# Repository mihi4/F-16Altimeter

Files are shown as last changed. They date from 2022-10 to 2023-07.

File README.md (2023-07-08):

# F-16 Altimeter

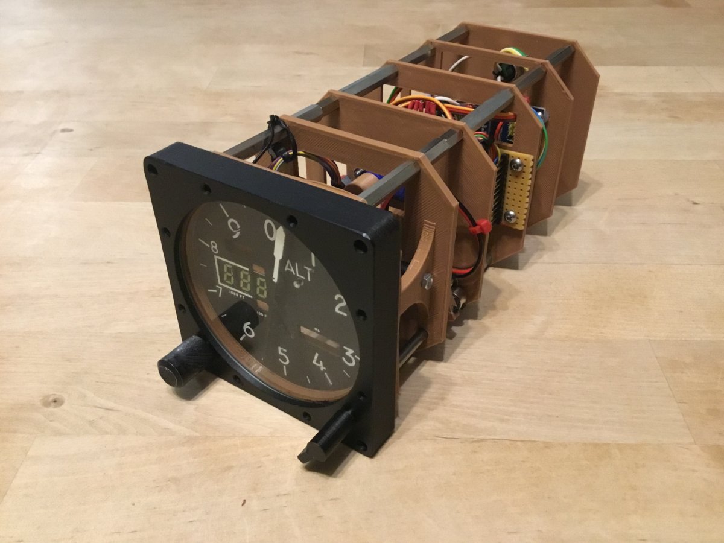
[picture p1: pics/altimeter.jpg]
Altimeter


All the files I created my altimeter from...

* The FCStd*-Files are all parts I created in FreeCAD.  
Not all of them are for 3Dprinting, some are just for reference.

* In the folder "3DprintFiles" are the exported parts as .3mf-files to use in your slicer.  
I'm not sure, if all the parts are up2date, since often I do some changes in FreeCAD without exporting the files afterwards.
Best strategy would be to export each part directly from the FreeCAD files.

* The "arduino" folder holds the sourcecode for the Arduino-side of [BMSAIT](https://github.com/mihi4/BMSAIT) by Robin "HummerX" Bruns.  
You can get the Windows program in the link above.
centerController.ini should be used as configuration file in BMSAIT.

The Nano will drive the Centerconsole instruments, except the ADI and HSI.  
Altimeter, the 2 ASI needles, 4 additional servos of VVI and AOA and the MarkerBeacon

- pin A5: input for rotary push to reset motor
- pin A6: switch for pneu/elec
- pin A7: input to zeroize the stepper 
- pins 2, 3: rotary encoder (2 interrupt pins)
- pins 4, 5, 6, 7: Altimeter continous x27 motor
- pins 8, 9, 10: max7210 for 4+3 7-segment displays
- pins 11, 12, 13, A1, A2, A3, A4: servos for PNEU flag, KIAS, MACH, VVI, AOA, VVIFlag, AOAFlag
- pin A0: marker beacon LED

There are no files for the connectionboard of the LEDMatrixBoard to the displays.  
You will have to find the specific pinout with a multimeter and then solder the right pin of the displays to it.

## !!! Use those files at your own risk !!!

All the files are free to use under the GNUGPLv3

If you find those files useful and would like to support me with an icecream, coffee or pizza, you can use paypal.me to do so ;)  
[Paypal.me](https://paypal.me/MichiHirczy)

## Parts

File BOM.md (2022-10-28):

## Hardware parts used and possible sources for it (mostly Aliexpress)

_needle shaft_: any 2mm rod you can find, I used 2mm spring steel since it was available

_needle motor_: X27.168 stepper motor, available all around the net

_needle zeroize sensor_: [Amazon](https://www.amazon.de/gp/product/B0817FM4BJ)

_PNEU flag shaft_: an 1mm steel rod, again, I'm using 1mm spring steel

_PNEU flag motor_: standard SG90 mini servo

_3 digit 7seg display_: 3312AW common cathode, 0.32" white, [Aliexpress](https://www.aliexpress.com/item/1005003689467554.html)

_5 digit 7seg display_: 0.23" common cathode display, white, [Aliexpress](https://www.aliexpress.com/item/1005003747393244.html)

_Arduino Nano_: nuff said ;)

_Extension board_: just google "Arduino Nano Extension Shield", buy wherever you want

_Display driver_: just google "max 7291 led matrix 8x8"

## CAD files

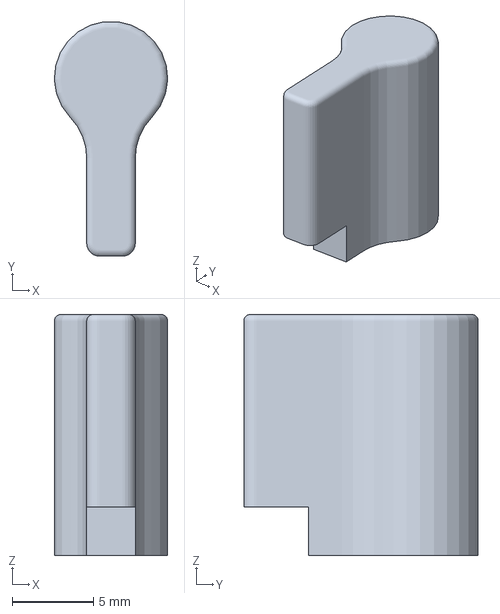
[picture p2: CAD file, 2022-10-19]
3DprintFiles/altimeter-pneuKnob.3mf
7.00 x 14.5 x 14.9 mm

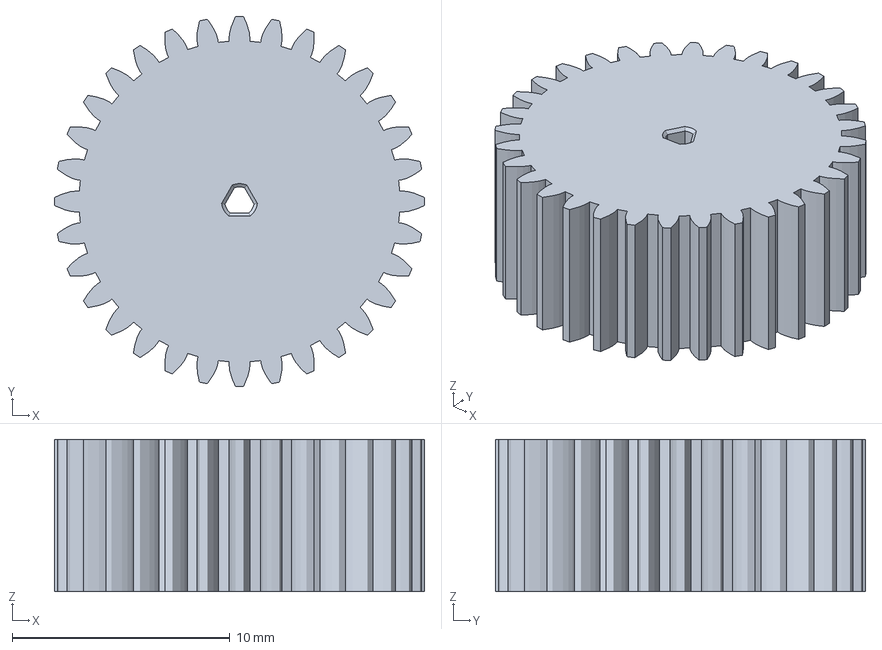
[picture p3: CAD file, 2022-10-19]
3DprintFiles/altimeter-GearBigMod0_5.3mf
17.0 x 17.0 x 7.00 mm

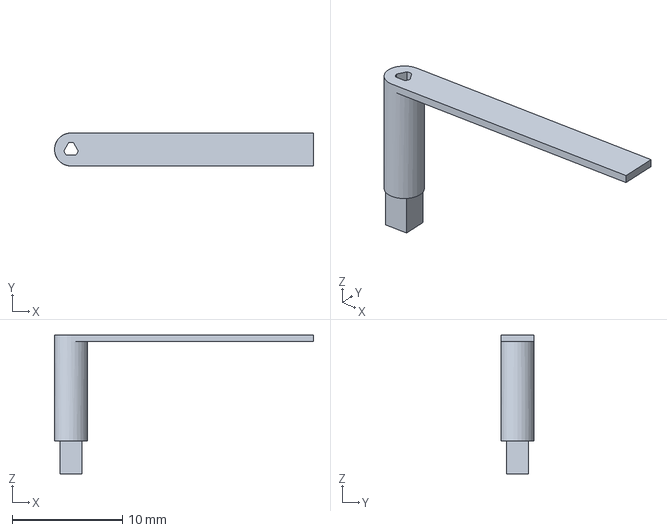
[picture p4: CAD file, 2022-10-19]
3DprintFiles/altimeter-axleConnector.3mf
23.5 x 3.00 x 12.6 mm

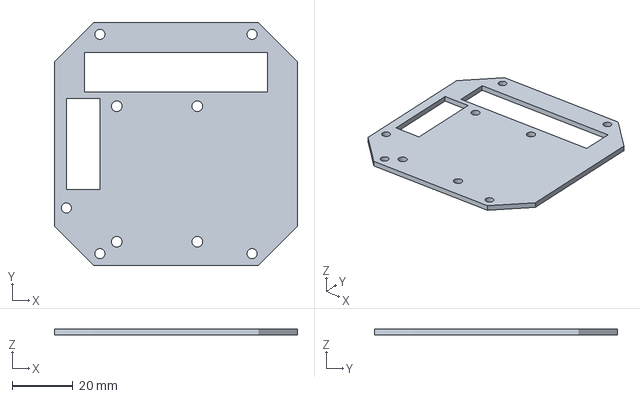
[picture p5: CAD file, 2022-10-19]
3DprintFiles/altimeterParts-MAX7219Plate.3mf
79.8 x 79.8 x 2.00 mm

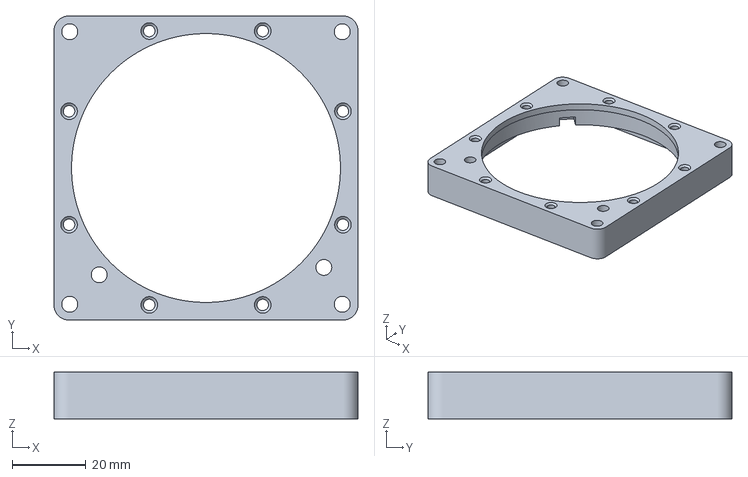
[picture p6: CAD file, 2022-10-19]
3DprintFiles/altimeterParts-Frontplate.3mf
82.5 x 82.5 x 12.7 mm

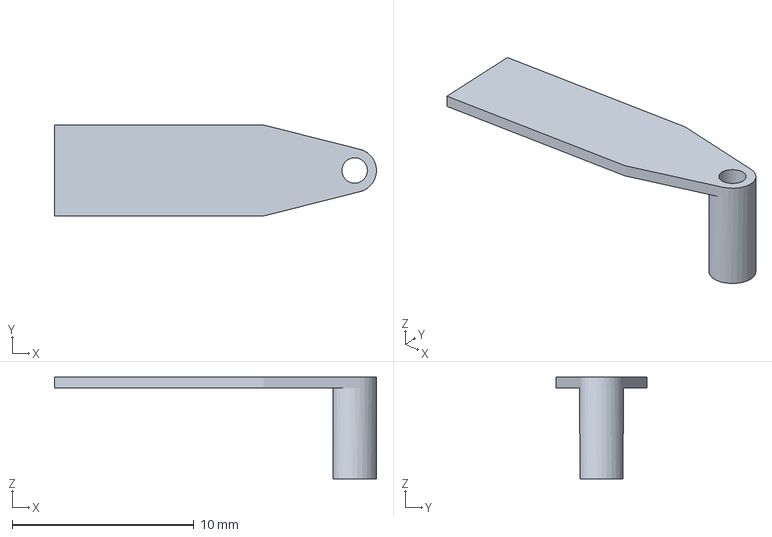
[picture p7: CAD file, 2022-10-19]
3DprintFiles/altimeter-pneuFlag.3mf
17.7 x 5.00 x 5.60 mm

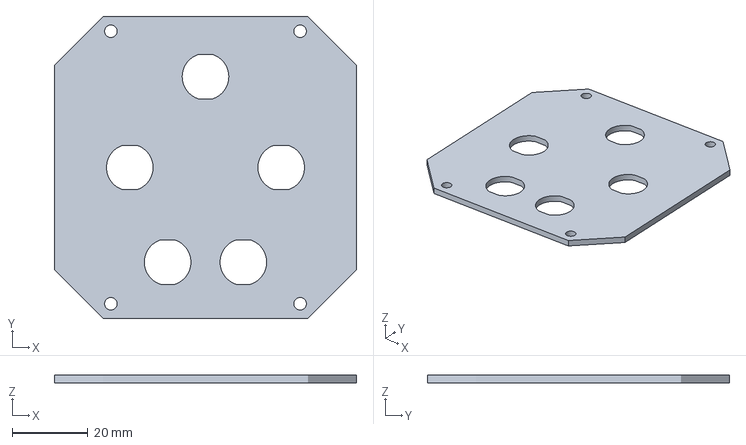
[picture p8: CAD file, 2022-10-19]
3DprintFiles/altimeterParts-ConnectorPlate.3mf
79.8 x 79.8 x 2.00 mm

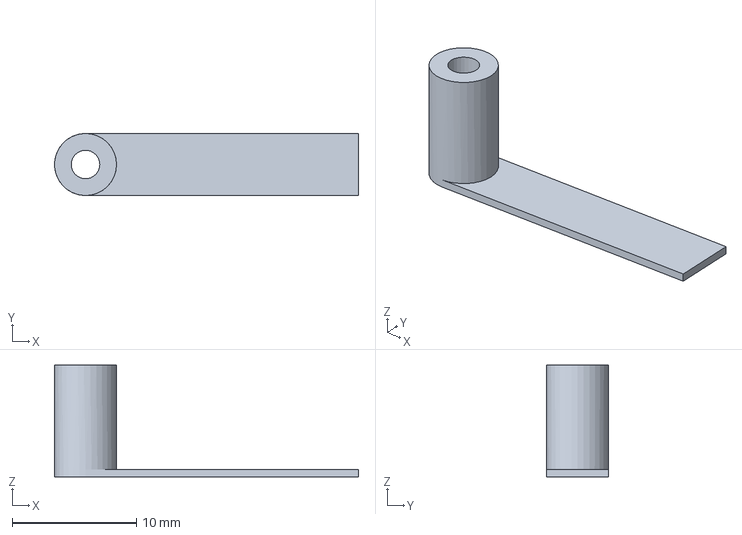
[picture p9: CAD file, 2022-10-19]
3DprintFiles/altimeter-SensorPin.3mf
24.5 x 5.00 x 9.00 mm

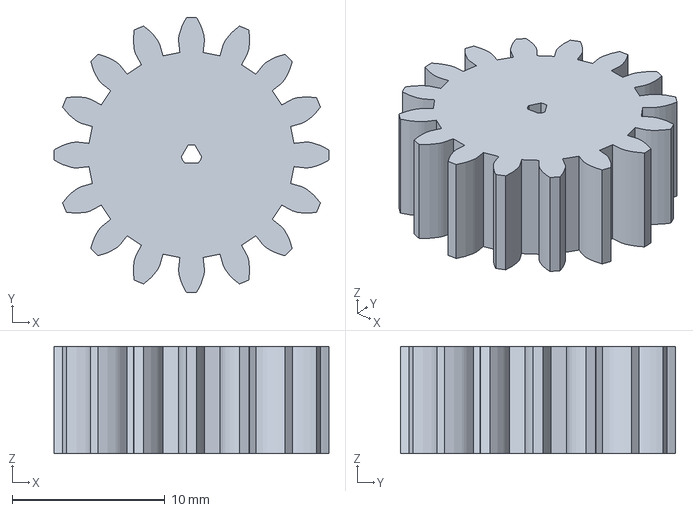
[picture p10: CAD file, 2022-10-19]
3DprintFiles/altimeter-GearBigStepper.3mf
18.0 x 18.0 x 7.00 mm

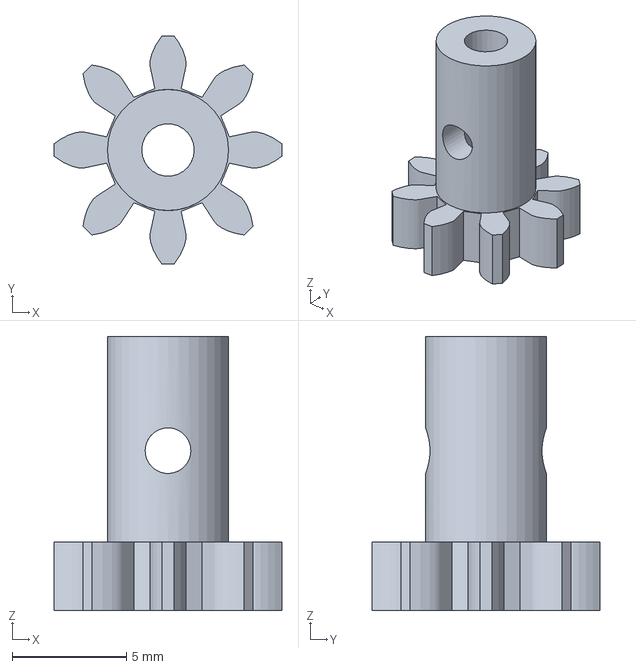
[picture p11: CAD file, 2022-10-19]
3DprintFiles/altimeter-gearSmallNeedle.3mf
9.99 x 9.99 x 12.0 mm

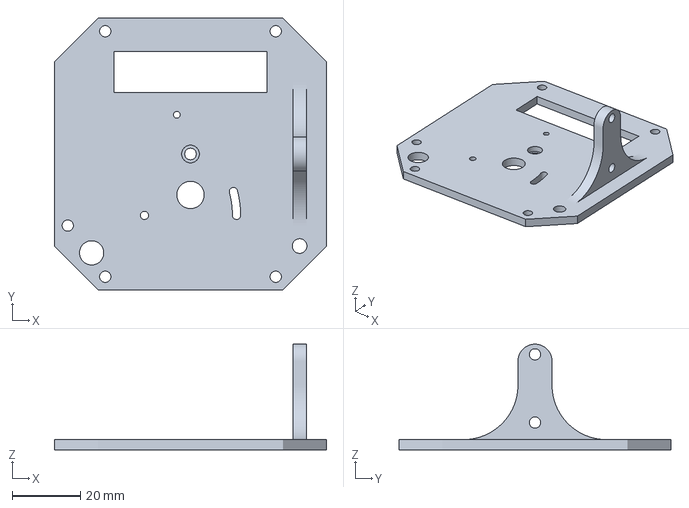
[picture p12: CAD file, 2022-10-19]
3DprintFiles/altimeterParts-StepperPlate.3mf
79.8 x 79.8 x 31.0 mm

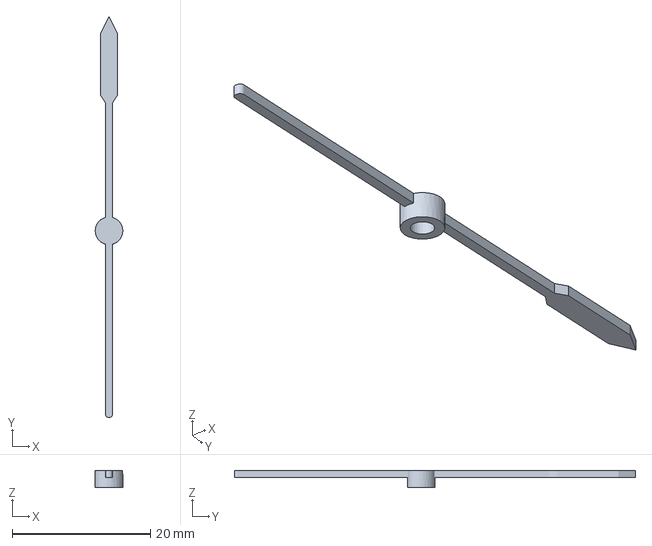
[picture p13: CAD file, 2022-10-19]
3DprintFiles/altimeter-Needle.3mf
4.00 x 58.0 x 2.50 mm

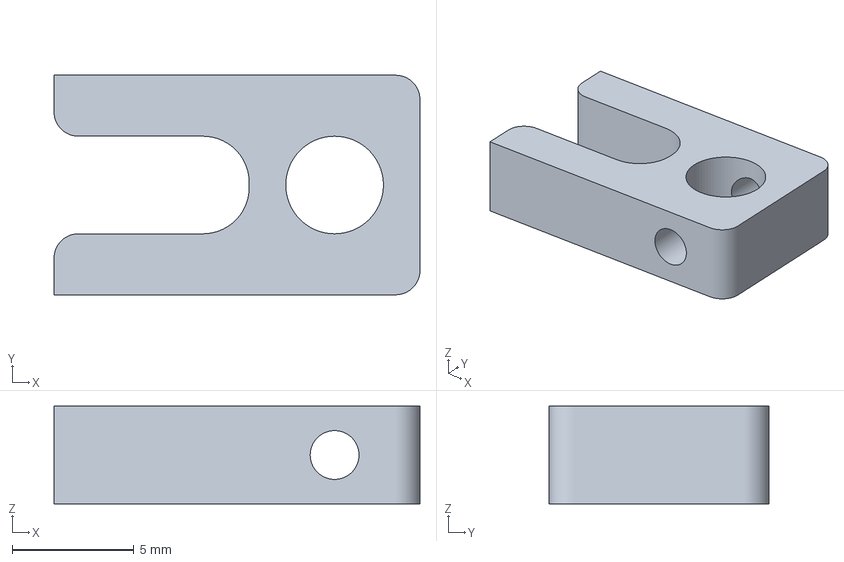
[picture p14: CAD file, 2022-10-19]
3DprintFiles/altimeter-pneuActivator.3mf
15.0 x 9.00 x 4.00 mm

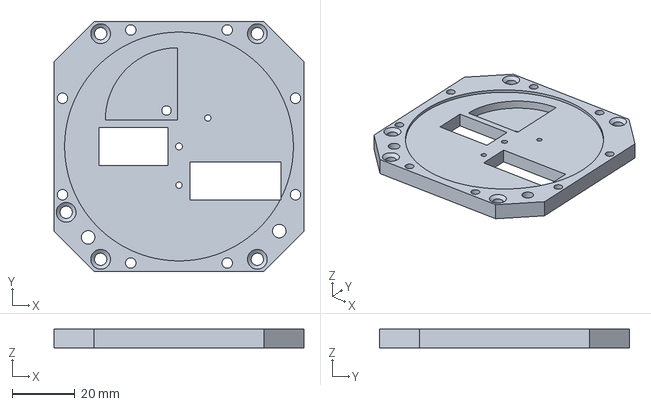
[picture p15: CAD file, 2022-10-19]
3DprintFiles/altimeterParts-Faceplate.3mf
79.8 x 79.8 x 6.00 mm

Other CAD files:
3DprintFiles/altimeterParts-Servoplate.3mf
3DprintFiles/altimeterParts-NanoShieldPlate.3mf
3DprintFiles/altimeter-GearSmallMod0_5.3mf
3DprintFiles/altimeter-GearSmallStandalone.3mf
3DprintFiles/altimeterParts-ServoAdapter.3mf

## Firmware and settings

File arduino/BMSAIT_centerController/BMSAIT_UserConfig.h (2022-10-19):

// Version: 1.3.11    29.3.22



//MODULE SELECTION - uncomment the modules you want to use.
   
  // FIXXXME #define LED               //drive LEDs
  //#define LEDMatrix         //drive LED Matrix using a MAX7219 controller
  //#define LED_MM5451        //drive LEDs through one or more MM5451 controller
  //#define LCD               //drive LCD display
  #define SSegMAX7219       //drive 7-Segment displays via MAX7219 controller
  //#define SSegTM1637        //drive 7-Segment displays via TM1367 controller
  //#define SLx2016           //drive 4-digit 5x7 dotmatrix modules
  #define ServoMotor        //drive servo motors directly connected to the arduino
  //#define ServoPWM          //drive multiple servo motors via pwm shield
  //#define StepperBYJ        //drive stepper motor 28BYJ-48
  //#define StepperX27        //drive stepper motor X27.168
  //#define CompassX27        //drive a compass with a Xxx.xxx -class stepper motor
  #define AltimeterX27      //drive the altimeter needle with a Xxx.xxx -class stepper motor
  //#define StepperVID        //drive multiple stepper motors X25.168 with a VID66-06 controller
  //#define MotorPoti         //motor-driven poti control
  //#define OLED              //display data on an OLED display
  //#define SpeedBrake        //Enable display of the SpeedBrake indicator on an 128x64 OLED display (DEDunino)
  //#define FuelFlowIndicator //Enable display of the FuelFlow indicator on an 128x64 OLED display (DEDunino)
  //#define DED_PFL           //Enable display of DED or PFL on an 254x64 OLED display (DEDunino)
  //#define Switches          //use the arduino to read switch positions and send keyboard commands
  //#define ButtonMatrix      //use the arduino to read switch positions and send keyboard commands
  #define RotEncoder        //use the arduino to read rotary encoders and send keyboard commands
  //#define AnalogAxis        //use the arduino to read analog resistors and sync this with a gamecontroller axis
  //#define Lighting          //software controlled backlighting
  //#define NewDevice         //placeholder. Use this line to activate your own code to drive other, specific hardware  


//BASIC SETTINGS
  #define BAUDRATE 57600         // serial connection speed
  #define POLLTIME 120           // set time between PULL data requests
  #define PULLTIMEOUT 50         // set time to wait for a requested data update defaut: 30ms
  //#define PRIORITIZE_OUTPUT    //uncomment this to put a stress on fast update of outputs (should be used for motors to allow smoother movements)
  //#define PRIORITIZE_INPUT     //uncomment this to put a stress on fast er poll of inputs (switches/Buttons) 
  const char ID[]= "BMSAIT_centerController"; //Set the ID for this arduino program. Use any string. The program will use this ID to check in with the BMSAIT windows application
 
//BOARD SELECTION

  //#define UNO         //uncomment this if this sketch will be loaded on an UNO
  #define NANO        //uncomment this if this sketch will be loaded on an NANO
  //#define MICRO       //uncomment this if this sketch will be loaded on an MICRO
  //#define LEONARDO    //uncomment this if this sketch will be loaded on an LEONARDO
  //#define MEGA        //uncomment this if this sketch will be loaded on an MEGA
  //#define DUE         //uncomment this if this sketch will be loaded on an DUE (connected via programming port)
  //#define DUE_NATIVE  //uncomment this if this sketch will be loaded on an DUE (connected via native port)
  //#define ESP         //uncomment this if this sketch will be loaded on an ESP32 or ESP8266
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

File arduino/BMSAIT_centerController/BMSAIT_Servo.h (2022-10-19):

// settings and functions to drive servo motors (directly connected to the arduino)
// V1.3.7 26.09.2021

//target= reference link to the line of the servodata table of this module
//ref2= not used
//ref3= not used
//ref4= not used
//ref5= not used

#include <Servo.h>

#define SERVODELAY 80
#define SERVOSLEEPTIME 20000

typedef struct
{
byte pIN;           //PIN the motor is connected to
byte p_ug;          //min arc for the motor (must not be less than 0!)
byte p_og;          //max arc for the motor (must not be more than 180!)
long a_ug;           //min absolut value that might be displayed (i.e.   0 for a speed indicator)
long a_og;           //max absolut value that might be displayed (i.e. 800 for a speed indicator)
long last;           //previous value
unsigned long lu;   //last update
} Servodata;


Servodata servodata[] =
{// pIN  p_ug  p_og  a_ug  a_og  last  lu
    //{A1,   0,   180,   0,   800,    0,   0},  // example speed indicator: {Servo on PIN=9, min arc =0, max arc=180, lowest possible value=0, highest value=800, past value=0, lastUpdate=0}
	{11,   0,   90,   0,   1,    0,   0},  // PNEU Flag
	{12,   0,   180,   0,   65535,    0,   0},  // KIAS	
	{13,   0,   180,   0,   20,    0,   0},  // mach
	{A1,   0,   180,   -1000,  1000,    0,   0},  // VVI usually -100 to 100; 
    {A2,   0,   180,   -350,   350,    0,   0},  // AOA  -35 to 35 deg; float value, see above
    //{A3,   0,   180,   0,   1,    0,   0},  // vvi data
	//{A4,   0,   180,   0,   1,    0,   0}  // AOA Flag */
};
const int SERVOZAHL = sizeof(servodata)/sizeof(servodata[0]);
Servo servo[SERVOZAHL];

void SetupServo()
{  
  for (byte lauf=0;lauf<SERVOZAHL;lauf++)
  {
    servo[lauf].attach(servodata[lauf].pIN);
    servo[lauf].write(servodata[lauf].p_ug);
    delay(500);
    servo[lauf].write(servodata[lauf].p_og);
    delay(500);
    servo[lauf].write(90);
    delay(500);
	servo[lauf].write(servodata[lauf].p_ug);
	delay(100);
    servo[lauf].detach();
  }
}

void Servo_FastUpdate()
{}

void Servo_Zeroize(bool mode)
{
  for (byte lauf=0;lauf<SERVOZAHL;lauf++)
  {
    if (!servo[lauf].attached())
        {servo[lauf].attach(servodata[lauf].pIN);}  //reactivate servo
    servo[lauf].write(servodata[lauf].p_ug);
    if (mode)
    {
      delay(500);
      servo[lauf].write(servodata[lauf].p_og);
      delay(5000);
      servo[lauf].write(servodata[lauf].p_og - servodata[lauf].p_ug);
      delay(5000);
    }
	servo[lauf].write(servodata[lauf].p_ug);
	delay(100);
    servo[lauf].detach();
  }
}


void UpdateServo(byte id)
{	
	/*if (debugmode){SendMessage("updatingServo",1);}
	if (debugmode){SendMessage(datenfeld[id].ID,1);}
	if (debugmode){SendMessage(datenfeld[id].wert,1);} */

  if (servodata[datenfeld[id].target].lu + SERVOSLEEPTIME < millis())
  {
    servo[datenfeld[id].target].detach();                        //disable servo if no new signal for more than 5 seconds
  }  
  else if (servodata[datenfeld[id].target].lu + SERVODELAY < millis())
  {
    servodata[datenfeld[id].target].lu = millis();  //pause servo
    
	long newValue = 0;
	if (datenfeld[id].format == 'f') { 
		float tmpVal = atof(datenfeld[id].wert);
		newValue = tmpVal * 10;
	} else {
		newValue = atol(datenfeld[id].wert);
	}
	
    if (servodata[datenfeld[id].target].last != newValue)
    {
      servodata[datenfeld[id].target].last = newValue; 
      if (!servo[datenfeld[id].target].attached())
        {servo[datenfeld[id].target].attach(servodata[datenfeld[id].target].pIN);}  //reactivate servo
      uint16_t winkel = map(servodata[datenfeld[id].target].last, servodata[datenfeld[id].target].a_ug, servodata[datenfeld[id].target].a_og, servodata[datenfeld[id].target].p_ug, servodata[datenfeld[id].target].p_og); 
	  
	  servo[datenfeld[id].target].write(winkel);          
    }
  }
}
